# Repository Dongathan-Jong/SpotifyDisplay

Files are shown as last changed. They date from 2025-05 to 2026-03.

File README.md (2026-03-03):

# Spotify Display

### Inspiration

Ever see one of those Spotify Car Things? They look amazing, and I would love to have one... Only problem is that they discontinued it and now costs upwards of $200. Why not make one myself?   

### Features

- Displays song + artist in real time
- Shows progress bar in real time
- You can pause / play / skip / go back with the buttons
- Runs on 3v3, decently low power consumption
- Has word wrap!!! (makes it so that the song/artist doesn't get cut off and creates a new line)
   
### Build process

This project is relatively simple, using a WEMOS ESP32 C3 mini, ST7735 1.8" Screen, and 3 keyboard switches for buttons.   

### Customization

You can change the icons, I used this tutorial to make the spotify / play / skip icons: https://www.instructables.com/Converting-Images-to-Flash-Memory-Iconsimages-for-/  
It works great, and the Spotify logo is 30x30, while all the other icons are 20x20.   

If you would like to modify the code, I put all of the spotify stuff into one single method, and its called in void loop().   

You can connect the screen relatively any way you would like, but you can change the pins here:   


As for the buttons, you can change the GPIO pins as well. Note that the LED pin for the c3 mini is 7 and the button is 9, so those basically cannot be used.    
  

Wiring:   
  

### Case 

I whipped this up in under an hour, the screen and esp32 are just hot glued in place, while the case uses m3 heatsets with m3 bolts to hold it together.   
There are 100% more work that can be done on this, but if it works it works :)  

### Setup

Before we start, install these libraries!  
- https://github.com/FinianLandes/SpotifyEsp32  
- Adafruit_ST7735  
- Adafruit_GFX  
Next, we will set up the client for Spotify.
- Hop over to https://developer.spotify.com/ and click on your profile in the top left and click dashboard.   
- Press create new app and you'll be prompted with this screen:   
  
- Name it anything you'd like and give it some random description. Add a random redirect URI for now. (we will change the redirect URI once we plug the ESP32 in)  
- Now, click on your newly created app and copy the client id + client secret and paste it into the code. Also, fill in the SSID and PASSWORD fields!
- Upload the code to the ESP and power it on, you should be prompted with a IP address on the screen or in the serial monitor.   
- Head back to the developer page and edit the app, and add in that IP as the callback URI. For example: I have 192.168.1.18 as my IP, the callback URI would be https://192.168.1.18/callback/, make sure to include the last slash!   
- You should be all good to go! Reset the ESP32 again and it should work once you login. Note you do not need to fill out the REFRESH_TOKEN field, it will be filled out by the code once you login!

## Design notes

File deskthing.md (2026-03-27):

# Desk Thing
Hey there! This is a intermediate project that will use display graphics and WiFi!   
  
Note that this is a intermediate project, step by step instructions will not be provided! Google and Youtube are your best friends during this journey. 
    
** Due to [spotify's updated API](https://developer.spotify.com/blog/2026-02-06-update-on-developer-access-and-platform-security) usage, the spotify desk thing is still available to those who have spotify premium. **  

Because of this, the tutorial will be more of project guidelines to guide you in the right direction!

### How this works

You will be creating a display that sits on your desk, hence the name desk thing! This device can do anything from display the weather, to your notifications, to a calendar.  
You will be required to use certain components and certain aspects of code. 

### Software Requirements
- The project must interact with the internet! Use the WiFi.h library or any other method you would like
- Thats about it for the software, as long as the code works with the final product, you're good. 
- You may ask: "how are we supposed to create code when we dont have components?" You can you simulation websites such as [circuitio](https://www.circuito.io/), [tinkercad](https://www.tinkercad.com/), and [wokwi](https://wokwi.com/)!

### Hardware Requirements

Your project must include the following
- User input (whether that be buttons, touch sensors, etc.)
- Microcontroller with WiFi (ESP32, RPI Pico, etc.)
- A screen (ST7735, OLED, Epaper)
- A case (CAD it! Use any platform you would like)
- You can choose to hand solder your project, or create a pcb for it!

### Case Requirements

Please refer to the [spotify display tutorial](https://github.com/Dongathan-Jong/SpotifyDisplay/blob/main/Tutorial.md) for the case preview, you may use the tutorial to get started, but you **MUST** personalize it and change the layout, otherwise **your project will not be approved**!

### Submission

To submit, make sure your repo has the following: 
- Code
- Case
- PCB (if needed)
- Hardware Components
- BOM
- README! Make sure this is descriptive, let us know if you are planning to hand wire / solder!

Good luck!
-

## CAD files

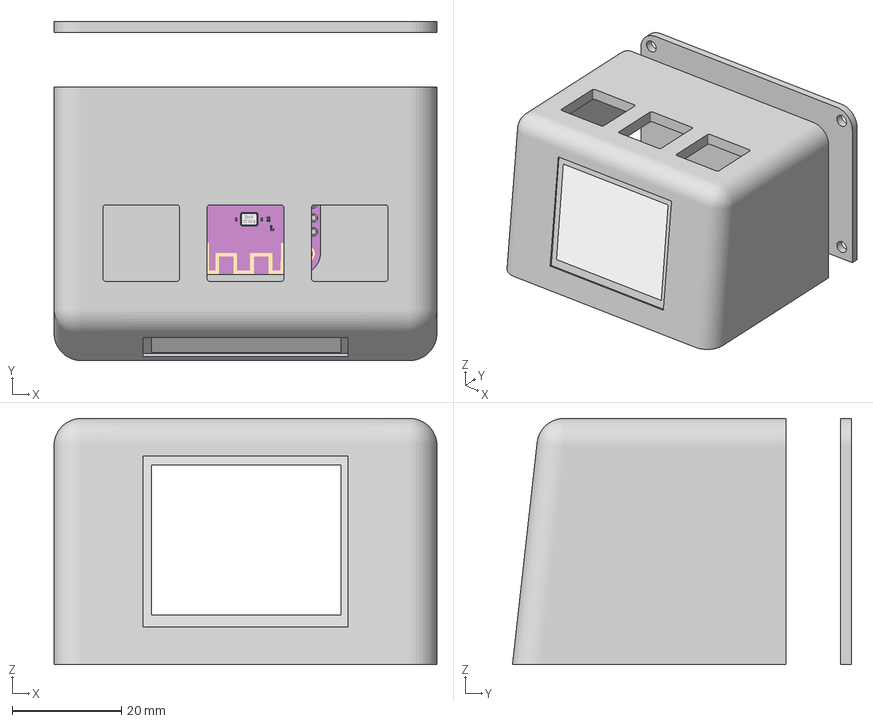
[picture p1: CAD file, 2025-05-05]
spotifyarduino.3mf
70.0 x 62.0 x 45.0 mm

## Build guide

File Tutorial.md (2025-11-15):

# Spotify Display - A Tutorial
Hello! This tutorial will be split into two parts, hardware and software. You will be learning about CAD, SPI communication, and Wifi!  

## Hardware
This device is relatively simple when it comes to hardware, you will need:  
* 1x ESP32 Board (any works, but we will be using the LOLIN C3 mini)
* 1x 1.8" TFT display (ST7735 or ILI9341)
* 3x Tactile switches (keyboard switches work too!)
* 4x M3 Heatset inserts
* Soldering iron (optional, or else you should use dupont cables)

For the case, it will be modelled in Fusion360! It is free for students [here](https://www.autodesk.com/education/edu-software/fusion)  

## Case
Download these parts to use in our CAD! 
* [Screen](https://grabcad.com/library/tft-display-1-8-1)
* [ESP32](https://grabcad.com/library/wemos-esp32-c3-mini-v1-0-0-1) (download the .step!)
* [Keyboard Switch](https://grabcad.com/library/outemu-mx-switch-1)

Start by creating a new project, then a new design. In this design, click on the upload button in the top left, and upload the downloaded assets above. Once uploaded, drag and drop the screen into your project. 
Create a new sketch by pressing this button:   
  

Select the plane you want to work on (XY plane)  
Create a rectangle by pressing the button to the right of where the sketch button used to be and create a 50x70mm rectangle:   


Click on that new sketched rectangle and press e, extrude it to 60mm  
Next, create a new sketch on the front side of the extruded body. Create another rectangle from the edge to the other edge of the screen: (43.5mm x  38mm)
  
Extrude that so that it turns into a hole through the case.  
Now, go to the other side (opposite of screen) and we will bore out the case, create another sketch and make it 5mm smaller on each edge (40mm x 60mm)  
  
Extrude this so that there is 2mm left on the screen part, (58mm)  
Now, let's make this look less ugly :)
select the top edges as such:   
  
Click fillet under the modify section, and set it to 5mm. This will round out the edges and make it look MUCH nicer.   
Next, add in the ESP32 you downloaded, right click on the component in the browser and click break link, and disable visibility for the header pins.   
  
Click 'm', and rotate the ESP32 so that it is in the right orientation, then click the point to point method: 
  
Select the first point as the bottom edge of the ESP32, and the second edge as the center bottom of the inside of the case as such:  
  
Now, we will work on the inside of the case. To get a better look into the middle, go under inspect and click on "Section Analysis":   
  
Place it on the top of the case and drawg it down until you can see into the case. It should look like such: 
  
Create walls on all 3 sides of the ESP to make sure it will not come out when plugging it in:  
  
Extrude the sketch 4mm and fillet the bottom side so that there are no overhangs during printing:   
  
This next part is optional, but highly recommended. Create a small lip so that the ESP can't escape vertically  
  
Thats it for the insides! Go back to your browser and under the Analysis folder, delete the Section Analysis you created.  

Create a new sketch on the very back of the case, and create 4 rectangles: 
* The outer edge of the case 
* The inside of the case 
* The port of the ESP
* The inside of the case with a gap of 2mm  
    
 
Next, create two small lines here:  
   

Extrude everything but the charging hole 2mm, and extrude the 2mm gap 4mm with the exclusion of the bottom edge: (blue = 2mm, red = 4mm) Make sure the operation on extrude is "New Body"! After the first extrude, the sketch will dissapear. You can go to the sketch folder under browser and change the visibility to view it again.  
   
   
You should be left with something like this:  
  
Thats all for the bottom of the case, You are ready to add keyboard switch holes! Move to the top of the case, and head over to https://kbplate.ai03.com/ and paste in ```["a","b","c"]```. Hit download DXF on the bottom, and upload that into Fusion. Drag and drop the DXF anywhere, and use free rotate so that it is parallel with the top of the case. Next, use the point to point move method to get it centered like so:   
   
Finally, extrude the 3 keyswitch holes so that they cut into the case. Your final product should like like so:   
   
   
Thats it for the case! Next, we will work on the software and API setup:  

## Spotify API setup
1. Hop over to https://developer.spotify.com/ and click on your profile in the top left and click dashboard.
2. Press create new app and you'll be prompted with this screen:   

3. Give it a name, write a small description, and add a random redirect URI for now! (we will change this later)
4.   Press save, then click on the app you just created, copy the Client ID and client secret and keep it aside for now. 

## Software
We will be using Arduino IDE, download it [here](https://www.arduino.cc/en/software/)  

This will be split into a few sections
* What you'll need
* Wifi connection
* Spotify library methods
* TFT screen setup
* Code example

### What you'll need
Before we start, a few things need to be installed. 
1. Follow [this](https://randomnerdtutorials.com/installing-the-esp32-board-in-arduino-ide-windows-instructions/) tutorial on how to install the ESP32 board in Arduino IDE
2. Install the following libraries
    * https://github.com/FinianLandes/SpotifyEsp32 (install as a .zip)
    * Adafruit_ST7735 
    * Adafruit_GFX  

Use the library manager to install the last two! Install all the pre-reqs when the pop-up shows after you click install.   

You're all done! In your new sketch, include the following:
```cpp
#include <Arduino.h>
#include <ArduinoJson.h>
#include <Adafruit_GFX.h>
#include <Adafruit_ST7735.h>
#include <WiFi.h>
#include <SpotifyEsp32.h>
#include <SPI.h>
```
Inside void setup(), include the following: 
```cpp
Serial.begin(115200);
```
This makes sure that the ESP32 can communicate with the computer over serial.

For general rule of thumb, if you would like to create a variable/object, it should go outside of any method, if you would like to setup something (e.g. it should only run once such as connecting to wifi), it should be in void setup(), if you would like something to run, it should be in void loop().

### Wifi Connection

We will need to store your WiFi credentials in the file, create two new lines under the included libraries: 

```cpp
char* SSID = "INSERT_SSID_HERE"
char* PASSWORD = "INSERT_PASSWORD_HERE"
```

These are two new variables that will hold your ssid/password

In the setup method (void setup), insert the following: 
```cpp
WiFi.begin(SSID, PASSWORD); // Attempt to connect to wifi 
Serial.print("Connecting to WiFi..."); // This will print into the console! 
while(WiFi.status() != WL_CONNECTED) // Checking if the wifi has connected
{
    delay(1000);
    Serial.print("."); // show a loading dot every second
}
Serial.printf("\nConnected!\n"); // Wifi connected!
```
Thats it! Now the ESP is connected to WiFi.  
If you would like to learn more behind the WiFi library, I would recommend checking out https://randomnerdtutorials.com/esp32-useful-wi-fi-functions-arduino/

### Spotify Library Methods

Create the following variables:
```cpp
const char* CLIENT_ID = "CLIENT_ID";
const char* CLIENT_SECRET = "CLIENT_SECRET";
```
Create your spotify object as such: 
```cpp
Spotify sp(CLIENT_ID, CLIENT_SECRET);
```
You can rename sp to anything you would like! This is the name of your object. 

To setup the connection between your ESP and spotify, it's relatively similar to WiFi! This block of code will connect the ESP to the spotify client. 

```cpp
sp.begin();
white(!sp.is_auth())
{
    sp.handle_cleint();
}
Serial.println("Connected to Spotify!");
```

Remember to put a delay(ms) at the end of the loop, spotify's API has a rate limit! (change ms with 1000 for 1s or 2000 for 2s)
#### General Methods
```cpp
sp.current_artist_names(); - returns String of all artists seperated by a ','
sp.current_track_name(); - returns String of song name
sp.start_resume_playback(); - Calling this method will pause/play the track
sp.skip(); - skips current track
sp.previous(); - goes to previous track
sp.is_playing(); - returns a boolean if something is playing currently
```
We will use these in an example!

### TFT Screen 
In this project, we will be using the ST7735 Screen. 

We need to define the pin variables that we will be connecting our screen to! Refer to the hardware section of the tutorial for the proper pin assignments. Create the variables as such:

```cpp
#define TFT_CS 1
#define TFT_RST 2
#define TFT_DC 3
#define TFT_SCLK 4
#define TFT_MOSI 5
```
Again, the numbers 1-5 will be changed based on your pin assignments on the ESP.

Create your screen object:
```cpp
Adafruit_ST7735 tft = Adafruit_ST7735(TFT_CS, TFT_DC, TFT_MOSI, TFT_SCLK, TFT_RST);
```
Similar to the spotify object setup, you can change "tft" to anything you would like.

In your setup, initiate the screen: 
```cpp
tft.initR(INITR_BLACKTAB); // the type of screen
tft.setRotation(1); // this makes the screen landscape! remove this line for portrait
Serial.println("TFT Initialized!");
tft.fillScreen(ST77XX_BLACK); // make sure there is nothing in the buffer
/*

INSERT WIFI SETUP HERE

*/

tft.setCursor(0,0); // make the cursor at the top left 
tft.write(WiFi.localIP().toString.c_str()); // print out IP on the screen
```
#### General Methods
```cpp
tft.write("STRING HERE"); - prints out the string 
tft.setCursor(x,y); - the screen is 160x128! Think of it as a x,y grid
tft.fillScreen(ST77XX_COLOR); - most of the main colors are here! 
tft.drawRect(Cursorx, Cursory, RectWidth, RectHeight, ST77XX_color); - draws a rectangle
tft.fillRect(Cursorx, Cursory, RectWidth, RectHeight, ST77XX_color); - fills in a rectangle
tft.setTextSize(integer); - try it out! Use 1,2,3, etc. 
```
Note that when printing strings from spotify, store the String into a variable, then properly format the string as such: 

```
tft.write(variable.toString.c_str());
```

It will not work otherwise and you will be met with an error!

### General Example

Now, we will combine everything to show a example!
Please keep in mind, this is a very bare bones program just to show the functionality of the code. 

```cpp
#include <Arduino.h>
#include <ArduinoJson.h>
#include <Adafruit_GFX.h>
#include <Adafruit_ST7735.h>
#include <WiFi.h>
#include <SpotifyEsp32.h>
#include <SPI.h>

#define TFT_CS 1
#define TFT_RST 2
#define TFT_DC 3
#define TFT_SCLK 4
#define TFT_MOSI 5

char* SSID = "YOUR WIFI SSID";
const char* PASSWORD = "YOUR WIFI PASSWORD";
const char* CLIENT_ID = "YOUR CLIENT ID FROM THE SPOTIFY DASHBOARD";
const char* CLIENT_SECRET = "YOUR CLIENT SECRET FROM THE SPOTIFY DASHBOARD";

String lastArtist;
String lastTrackame;

Spotify sp(CLIENT_ID, CLIENT_SECRET);
Adafruit_ST7735 tft = Adafruit_ST7735(TFT_CS, TFT_DC, TFT_MOSI, TFT_SCLK, TFT_RST);

void setup() {
    Serial.begin(115200);
    
    tft.initR(INITR_BLACKTAB); // the type of screen
    tft.setRotation(1); // this makes the screen landscape! remove this line for portrait
    Serial.println("TFT Initialized!");
    tft.fillScreen(ST77XX_BLACK); // make sure there is nothing in the buffer
    
    WiFi.begin(SSID, PASSWORD); 
    Serial.print("Connecting to WiFi..."); 
    while(WiFi.status() != WL_CONNECTED)
    {
        delay(1000);
        Serial.print(".");
    }
    Serial.printf("\nConnected!\n");

    tft.setCursor(0,0); // make the cursor at the top left 
    tft.write(WiFi.localIP().toString.c_str()); // print out IP on the screen
    
    sp.begin();
    while(!sp.is_auth()){
        sp.handle_client();
    }
    Serial.println("Authenticated");
}

void loop()
{
    String currentArtist = sp.current_artist_names();
    String currentTrackname = sp.current_track_name();
    
    if (lastArtist != currentArtist && currentArtist != "Something went wrong" && !currentArtist.isEmpty()) {
        tft.fillScreen(ST77XX_BLACK);
        lastArtist = currentArtist;
        Serial.println("Artist: " + lastArtist);
        tft.setCursor(10,10);
        tft.write(lastArtist.toString().c_str());
    }
    
    if (lastTrackname != currentTrackname && currentTrackname != "Something went wrong" && currentTrackname != "null") {
        lastTrackname = currentTrackname;
        Serial.println("Track: " + lastTrackname);
        tft.setCursor(10,40);
        tft.write(lastTrackname.toString().c_str());
    }
    delay(2000);
}
```
Thats all! If you would like to learn more about what methods / customizations you can do, check out these pages: 
* https://github.com/FinianLandes/SpotifyEsp32/tree/main/examples
    * This has more examples!
* https://github.com/FinianLandes/SpotifyEsp32/blob/main/src/SpotifyEsp32.cpp
    * All the methods and what they return for the spotify library
* https://learn.adafruit.com/adafruit-gfx-graphics-library/overview
    * All the graphics that are possible with the ST7735 screen (fonts, colors, etc.)

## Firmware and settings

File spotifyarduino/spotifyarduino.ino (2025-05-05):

#include <ArduinoJson.h>
#include <Adafruit_GFX.h>
#include <Adafruit_ST7735.h>
#include <SPI.h>
#include <Arduino.h>
#include <WiFi.h>
#include <SpotifyEsp32.h>

boolean oneTime = true;
boolean secondLine = false; 
boolean secondLineTrack = false;
int progressCheck = 0;
boolean playing;
boolean getTop = true;
boolean topPlayed = false;
String lastArtist;
String lastTrackname;

// CHANGE ALL THESE TO CONTAIN YOUR INFO! 
char* SSID = "";
const char* PASSWORD = "";
const char* CLIENT_ID = "";
const char* CLIENT_SECRET = "";
const char* REFRESH_TOKEN = "";

// CHANGE BUTTON PINS HERE
#define leftButton 10
#define middleButton 8
#define rightButton 6

// CHANGE SCREEN PINS HERE
#define TFT_CS 5
#define TFT_RST 4
#define TFT_DC 3
#define TFT_SCLK 2
#define TFT_MOSI 1

const unsigned char spotifyLogo[] PROGMEM = {
  0x00, 0x07, 0x80, 0x00,
  0x00, 0x3f, 0xf0, 0x00,
  0x00, 0xff, 0xfc, 0x00,
  0x03, 0xff, 0xff, 0x00,
  0x07, 0xff, 0xff, 0x80,
  0x0f, 0xff, 0xff, 0xc0,
  0x1f, 0xff, 0xff, 0xe0,
  0x1f, 0xff, 0xff, 0xe0,
  0x3f, 0x80, 0x7f, 0xf0,
  0x38, 0x00, 0x03, 0xf0,
  0x78, 0x00, 0x00, 0xf8,
  0x78, 0xff, 0xc0, 0x78,
  0x7f, 0xff, 0xf8, 0x38,
  0xff, 0x80, 0x7f, 0x7c,
  0xfc, 0x00, 0x0f, 0xfc,
  0xfc, 0x00, 0x03, 0xfc,
  0xff, 0xff, 0xe0, 0xfc,
  0x7f, 0xff, 0xf8, 0xf8,
  0x7e, 0x00, 0x3f, 0xf8,
  0x7e, 0x00, 0x0f, 0xf8,
  0x3f, 0xff, 0x83, 0xf0,
  0x3f, 0xff, 0xf3, 0xf0,
  0x1f, 0xff, 0xff, 0xe0,
  0x1f, 0xff, 0xff, 0xe0,
  0x0f, 0xff, 0xff, 0xc0,
  0x07, 0xff, 0xff, 0x80,
  0x03, 0xff, 0xff, 0x00,
  0x00, 0xff, 0xfc, 0x00,
  0x00, 0x3f, 0xf0, 0x00,
  0x00, 0x07, 0x80, 0x00
};

const unsigned char playIcon[] PROGMEM = {
  0x00, 0x00, 0x00,
  0x00, 0x00, 0x00,
  0x00, 0xf0, 0x00,
  0x03, 0xfc, 0x00,
  0x07, 0xff, 0x00,
  0x0f, 0xff, 0x00,
  0x1f, 0xff, 0x80,
  0x1e, 0x67, 0x80,
  0x3e, 0x67, 0xc0,
  0x3e, 0x67, 0xc0,
  0x3e, 0x67, 0xc0,
  0x3e, 0x67, 0xc0,
  0x1e, 0x67, 0x80,
  0x1f, 0xff, 0x80,
  0x0f, 0xff, 0x00,
  0x07, 0xfe, 0x00,
  0x03, 0xfc, 0x00,
  0x00, 0xf0, 0x00,
  0x00, 0x00, 0x00,
  0x00, 0x00, 0x00
};

const unsigned char pauseIcon[] PROGMEM = {
  0x00, 0x00, 0x00,
  0x00, 0x00, 0x00,
  0x00, 0xf0, 0x00,
  0x03, 0xfc, 0x00,
  0x07, 0xff, 0x00,
  0x0f, 0xff, 0x00,
  0x1f, 0xff, 0x80,
  0x1f, 0x3f, 0x80,
  0x3e, 0x0f, 0xc0,
  0x3e, 0x07, 0xc0,
  0x3e, 0x07, 0xc0,
  0x3e, 0x0f, 0xc0,
  0x1f, 0x3f, 0x80,
  0x1f, 0xff, 0x80,
  0x0f, 0xff, 0x00,
  0x07, 0xfe, 0x00,
  0x03, 0xfc, 0x00,
  0x00, 0xf0, 0x00,
  0x00, 0x00, 0x00,
  0x00, 0x00, 0x00
};

const unsigned char prev[] PROGMEM = {
  0x00, 0xf0, 0x00,
  0x03, 0xfc, 0x00,
  0x0c, 0x03, 0x00,
  0x18, 0x01, 0x80,
  0x30, 0x00, 0xc0,
  0x20, 0x00, 0x40,
  0x40, 0x00, 0x20,
  0x42, 0x04, 0x20,
  0xc2, 0x1c, 0x30,
  0xc2, 0x64, 0x30,
  0xc2, 0x64, 0x30,
  0xc2, 0x1c, 0x30,
  0x42, 0x04, 0x20,
  0x40, 0x00, 0x20,
  0x20, 0x00, 0x40,
  0x30, 0x00, 0xc0,
  0x18, 0x01, 0x80,
  0x0c, 0x03, 0x00,
  0x03, 0xfc, 0x00,
  0x00, 0xf0, 0x00
};

const unsigned char next[] PROGMEM = {
  0x00, 0xf0, 0x00,
  0x03, 0xfc, 0x00,
  0x0c, 0x03, 0x00,
  0x18, 0x01, 0x80,
  0x30, 0x00, 0xc0,
  0x20, 0x00, 0x40,
  0x40, 0x00, 0x20,
  0x42, 0x04, 0x20,
  0xc3, 0x84, 0x30,
  0xc2, 0x64, 0x30,
  0xc2, 0x64, 0x30,
  0xc3, 0x84, 0x30,
  0x42, 0x04, 0x20,
  0x40, 0x00, 0x20,
  0x20, 0x00, 0x40,
  0x30, 0x00, 0xc0,
  0x18, 0x01, 0x80,
  0x0c, 0x03, 0x00,
  0x03, 0xfc, 0x00,
  0x00, 0xf0, 0x00
};


Adafruit_ST7735 tft = Adafruit_ST7735(TFT_CS, TFT_DC, TFT_MOSI, TFT_SCLK, TFT_RST);

Spotify sp(CLIENT_ID, CLIENT_SECRET);

void setup() {
  pinMode(8, INPUT_PULLUP);
  pinMode(9, INPUT_PULLUP);
  pinMode(10, INPUT_PULLUP);
  tft.initR(INITR_BLACKTAB);
  tft.setRotation(1);
  Serial.println("tft good");

  tft.fillScreen(ST77XX_BLACK);

  tft.setTextSize(1.8);

  Serial.begin(115200);
  connect_to_wifi();

  tft.setCursor(30, 50);
  tft.write("SSID: ");
  tft.write(SSID);

  tft.setCursor(30, 70);
  tft.write("IP: ");
  tft.write(WiFi.localIP().toString().c_str());

  Serial.println(WiFi.localIP());

  sp.begin();
  while (!sp.is_auth()) {
    sp.handle_client();
  }


  Serial.println("Authenticated");
  tft.fillScreen(ST77XX_BLACK);

  playing = sp.is_playing();

  tft.drawBitmap(5, 2, spotifyLogo, 30, 30, ST77XX_GREEN);

  if (sp.is_playing()) {
    tft.drawBitmap(70, 100, playIcon, 20, 20, ST77XX_WHITE);
  } else {
    tft.drawBitmap(70, 100, pauseIcon, 20, 20, ST77XX_WHITE);
  }

  tft.drawBitmap(25, 100, prev, 20, 20, ST77XX_WHITE);
  tft.drawBitmap(115, 100, next, 20, 20, ST77XX_WHITE);
}

void loop()
{
  
    normalScreen();
  
}

void normalScreen() 
{

  checkInput();

  tft.setTextSize(1.5);
  String currentArtist = sp.current_artist_names();
  String currentTrackname = sp.current_track_name();
  checkInput();

  if (lastArtist != currentArtist && currentArtist != "null" && !currentArtist.isEmpty() && currentTrackname != "null" && lastTrackname != currentTrackname) {
    lastArtist = currentArtist;
    lastTrackname = currentTrackname;
    tft.setTextSize(1.9);

    checkInput();
    if (lastArtist.length() < 18) {
      Serial.println("Artist: " + lastArtist);
      tft.fillRect(40, 65, 140, 20, ST77XX_BLACK);
      tft.setCursor(40, 65);
      tft.write(lastArtist.c_str());
      checkInput();
    } else if (lastArtist.charAt(10) == ' ') {
      Serial.println("Artist: " + lastArtist);
      tft.fillRect(40, 65, 140, 20, ST77XX_BLACK);
      tft.setCursor(40, 65);
      tft.write(lastArtist.substring(0, 10).c_str());
      tft.setCursor(40, 75);
      tft.write(lastArtist.substring(11, lastArtist.length()).c_str());
      checkInput();
    } else {
      int tempCounter = 0;
      int tempCharCount = 0;

      //check # of words
      for (int i = 0; i < 18; i++) {
        if (lastArtist.charAt(i) == ' ') {
          tempCounter++;
        }
        checkInput();
      }

      int tempWordCount = 0;
      String firstLineArtist = "";

      for (int i = 0; i < 18; i++) {
        if (tempWordCount != tempCounter) {
          firstLineArtist += lastArtist.charAt(i);
          if (lastArtist.charAt(i) == ' ') {
            tempWordCount++;
          }
        }
        checkInput();
      }
      checkInput();
      Serial.println("Artist: " + lastArtist);
      tft.fillRect(40, 65, 140, 20, ST77XX_BLACK);
      tft.setCursor(40, 65);
      tft.write(firstLineArtist.c_str());
      tft.setCursor(40, 75);
      tft.write(lastArtist.substring(firstLineArtist.length(), lastArtist.length()).c_str());
    }

    checkInput();
    if (lastTrackname.length() <= 10) {
      Serial.println("Track: " + lastTrackname);
      tft.fillRect(35, 0, 145, 40, ST77XX_BLACK);
      tft.setTextSize(2);
      tft.setCursor(40, 10);
      tft.write(lastTrackname.c_str());
      checkInput();
    } else if (lastTrackname.charAt(10) == ' ' && lastTrackname.length() <= 30) {
      tft.fillRect(35, 0, 145, 40, ST77XX_BLACK);
      tft.setTextSize(2);
      tft.setCursor(40, 3);
      tft.write(lastTrackname.substring(0, 10).c_str());
      tft.setTextSize(1.5);
      tft.setCursor(40, 20);
      tft.write(lastTrackname.substring(11, lastTrackname.length()).c_str());
      checkInput();
    } else {
      int counter = 0;
      int characterCount = 0;
      for (int i = 0; i < 10; i++) {
        if (lastTrackname.charAt(i) == ' ') {
          counter++;
          characterCount++;
        } else {
          characterCount++;
        }
      }

      int wordCount = 0;
      String theTrack = "";
      for (int i = 0; i < characterCount; i++) {
        if (wordCount != counter) {
          theTrack += lastTrackname.charAt(i);
          if (lastTrackname.charAt(i) == ' ') {
            wordCount++;
          }
        }
      }
      checkInput();
      tft.fillRect(35, 0, 145, 40, ST77XX_BLACK);
      tft.fillRect(0, 36, 180, 19, ST77XX_BLACK);


      String restOfTrack = lastTrackname.substring(theTrack.length(), lastTrackname.length());

      if (restOfTrack.length() <= 20) {
        tft.setTextSize(2);
        tft.setCursor(40, 5);
        tft.write(theTrack.c_str());
        tft.setTextSize(1.5);
        tft.setCursor(40, 22);
        tft.write(restOfTrack.c_str());
      } else if (restOfTrack.charAt(20) == ' ') {
        tft.setTextSize(2);
        tft.setCursor(40, 0);
        tft.write(theTrack.c_str());
        tft.setTextSize(1.5);
        tft.setCursor(40, 17);
        Serial.println(restOfTrack.substring(0, 19));
        tft.write(restOfTrack.substring(0, 20).c_str());
        tft.setCursor(40, 27);
        tft.write(restOfTrack.substring(21, restOfTrack.length()).c_str());
      } else {

        tft.setTextSize(2);
        tft.setCursor(40, 0);
        tft.write(theTrack.c_str());
        tft.setTextSize(1.5);
        tft.setCursor(40, 17);
        int restCounter = 0;
        int restCharacterCount = 0;

        for (int i = 0; i < 20; i++) {
          if (restOfTrack.charAt(i) == ' ') {
            restCounter++;
          }
        }

        int restWordCount = 0;
        String thirdLine = "";
        for (int i = 0; i < 20; i++) {
          if (restWordCount != restCounter) {
            thirdLine += restOfTrack.charAt(i);
            if (restOfTrack.charAt(i) == ' ') {
              restWordCount++;
            }
          }
        }

        tft.write(thirdLine.c_str());
        tft.setCursor(40, 27);
        tft.write(restOfTrack.substring(thirdLine.length(), restOfTrack.length()).c_str());
      }

      
    }
    tft.fillRect(0,124,180,4,ST77XX_BLACK);
    checkInput();
  }

  if (progressCheck == 2) {
    checkProgress();
    progressCheck = 0;
  } else {
    progressCheck++;
  }
}

void connect_to_wifi() {
  WiFi.begin(SSID, PASSWORD);
  Serial.print("Connecting to WiFi...");
  while (WiFi.status() != WL_CONNECTED) {
    delay(1000);
    Serial.print(".");
  }
  Serial.printf("\nConnected to WiFi\n");
}

void checkProgress() {
  StaticJsonDocument<200> filter;
  filter["item"]["duration_ms"] = true;
  filter["progress_ms"] = true;

  response r = sp.current_playback_state(filter);

  int progressMs = r.reply["progress_ms"];
  int durationMs = r.reply["item"]["duration_ms"];
  
  double percentage = (double)progressMs/(double)durationMs;
  Serial.println(progressMs);
  Serial.println(durationMs);
  Serial.println(percentage);
  tft.setCursor(0,124);
  tft.fillRect(0,124,(int)(160*percentage),4, ST77XX_GREEN);
}

void checkInput() {
  if (digitalRead(middleButton) == LOW) {
    Serial.println("pause/unpause!");
    if (playing) {
      tft.fillRect(70, 100, 20, 20, ST77XX_BLACK);
      tft.drawBitmap(70, 100, pauseIcon, 20, 20, ST77XX_WHITE);
      sp.pause_playback();
      playing = false;
    } else {
      tft.fillRect(70, 100, 20, 20, ST77XX_BLACK);
      tft.drawBitmap(70, 100, playIcon, 20, 20, ST77XX_WHITE);
      sp.start_resume_playback();
      playing = true;
    }
  }

  if (digitalRead(rightButton) == LOW) {
    tft.drawBitmap(115, 100, next, 20, 20, ST77XX_GREEN);
    sp.skip();
    tft.drawBitmap(115, 100, next, 20, 20, ST77XX_WHITE);
  }
  
  if (digitalRead(leftButton) == LOW) {
    tft.drawBitmap(25, 100, prev, 20, 20, ST77XX_GREEN);
    sp.previous();
    tft.drawBitmap(25, 100, prev, 20, 20, ST77XX_WHITE);
  }
}

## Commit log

2025-11-15 Create tutorial for Spotify display with ESP32
    Added a comprehensive tutorial for building a Spotify display using ESP32, including hardware setup, software requirements, and example code.
2025-11-15 Enhance tutorial with fillet and ESP32 instructions
    Added instructions for filleting edges and working with ESP32.
2025-11-15 Enhance Tutorial with case analysis steps and images
    Added additional instructions and images for case analysis.
2025-11-15 Enhance tutorial with case design instructions
    Added detailed instructions for creating walls and extruding the sketch inside the case for the ESP32.
2026-03-03 Update README with wiring image and GPIO details
    Added wiring image and updated button GPIO pin information.
